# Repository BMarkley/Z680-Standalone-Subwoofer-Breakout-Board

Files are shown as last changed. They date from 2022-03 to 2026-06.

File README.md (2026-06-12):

# Z680-Standalone-Subwoofer-Breakout-Board
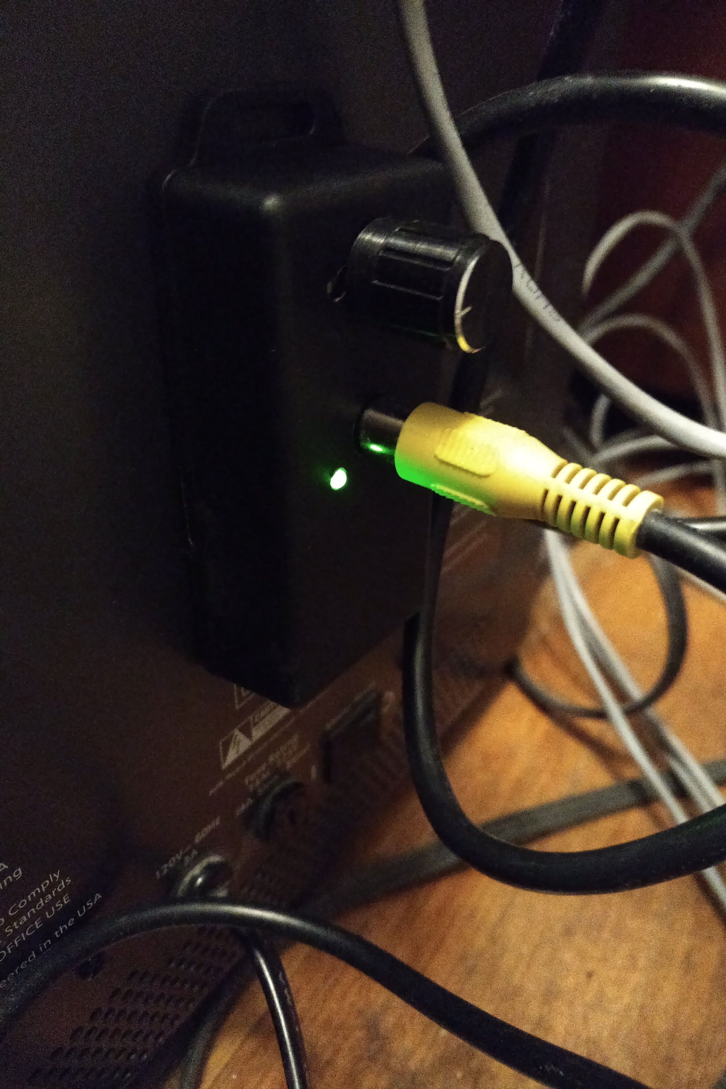
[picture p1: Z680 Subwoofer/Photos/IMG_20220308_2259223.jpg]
materials


This is a pcb and circuit for repurposing the subwoofer in the Z680 Logitech speakers system with an aftermarket receiver. Good for keeping these speakers in service after the control pod fails.

The PCB has been tested and works great, but the design is provided with no garauntees or warranty. You are liable for your own actions.

Notes on the LED and enclosure: 

1: The enclosure took a little trial and error so use your best judgement. The original plan for the LED was to lave it illuminate the phono jack but the LED I selected was not bright enough to work like that. I had to bring it to the exterior of the case. Inconsistencies in the photos are just the trial and error process. 

2: I needed to use 2 washers on the potentiometer to get the Dsub connector to be at the correct depth.

3: You may want to use double sided tape to secure the final product to the back of the subwoofer. 

Licensing: Open Hardware licensed under the Creative Commons BY-SA 4.0 License

You are free to:
Share — copy and redistribute the material in any medium or format
Adapt — remix, transform, and build upon the material
The licensor cannot revoke these freedoms as long as you follow the license terms.
Under the following terms:
Attribution — You must give appropriate credit, provide a link to the license, and indicate if changes were made. You may do so in any reasonable manner, but not in any way that suggests the licensor endorses you or your use.

NonCommercial — You may not use the material for commercial purposes.

ShareAlike — If you remix, transform, or build upon the material, you must distribute your contributions under the same license as the original.

No additional restrictions — You may not apply legal terms or technological measures that legally restrict others from doing anything the license permits.

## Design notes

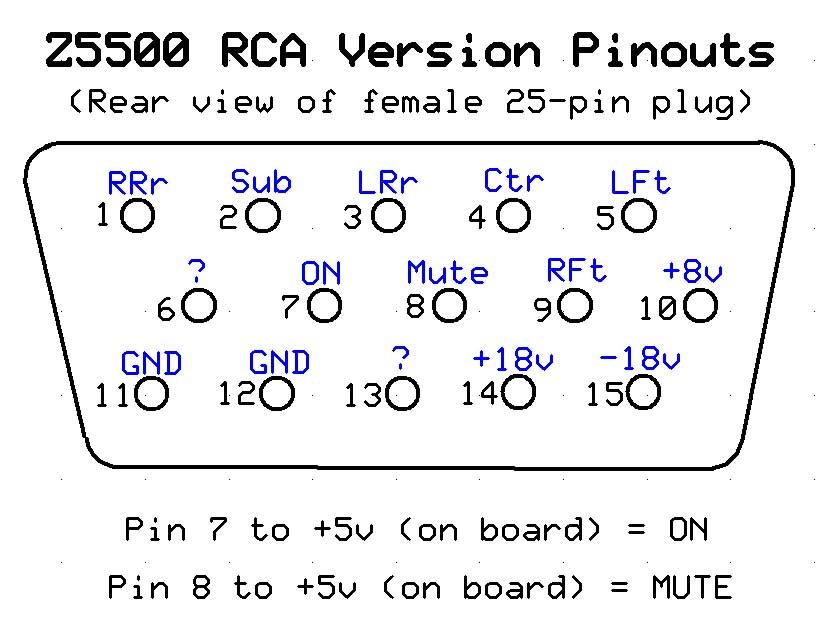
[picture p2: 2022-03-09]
Z680 Subwoofer/Development/z5500.jpg

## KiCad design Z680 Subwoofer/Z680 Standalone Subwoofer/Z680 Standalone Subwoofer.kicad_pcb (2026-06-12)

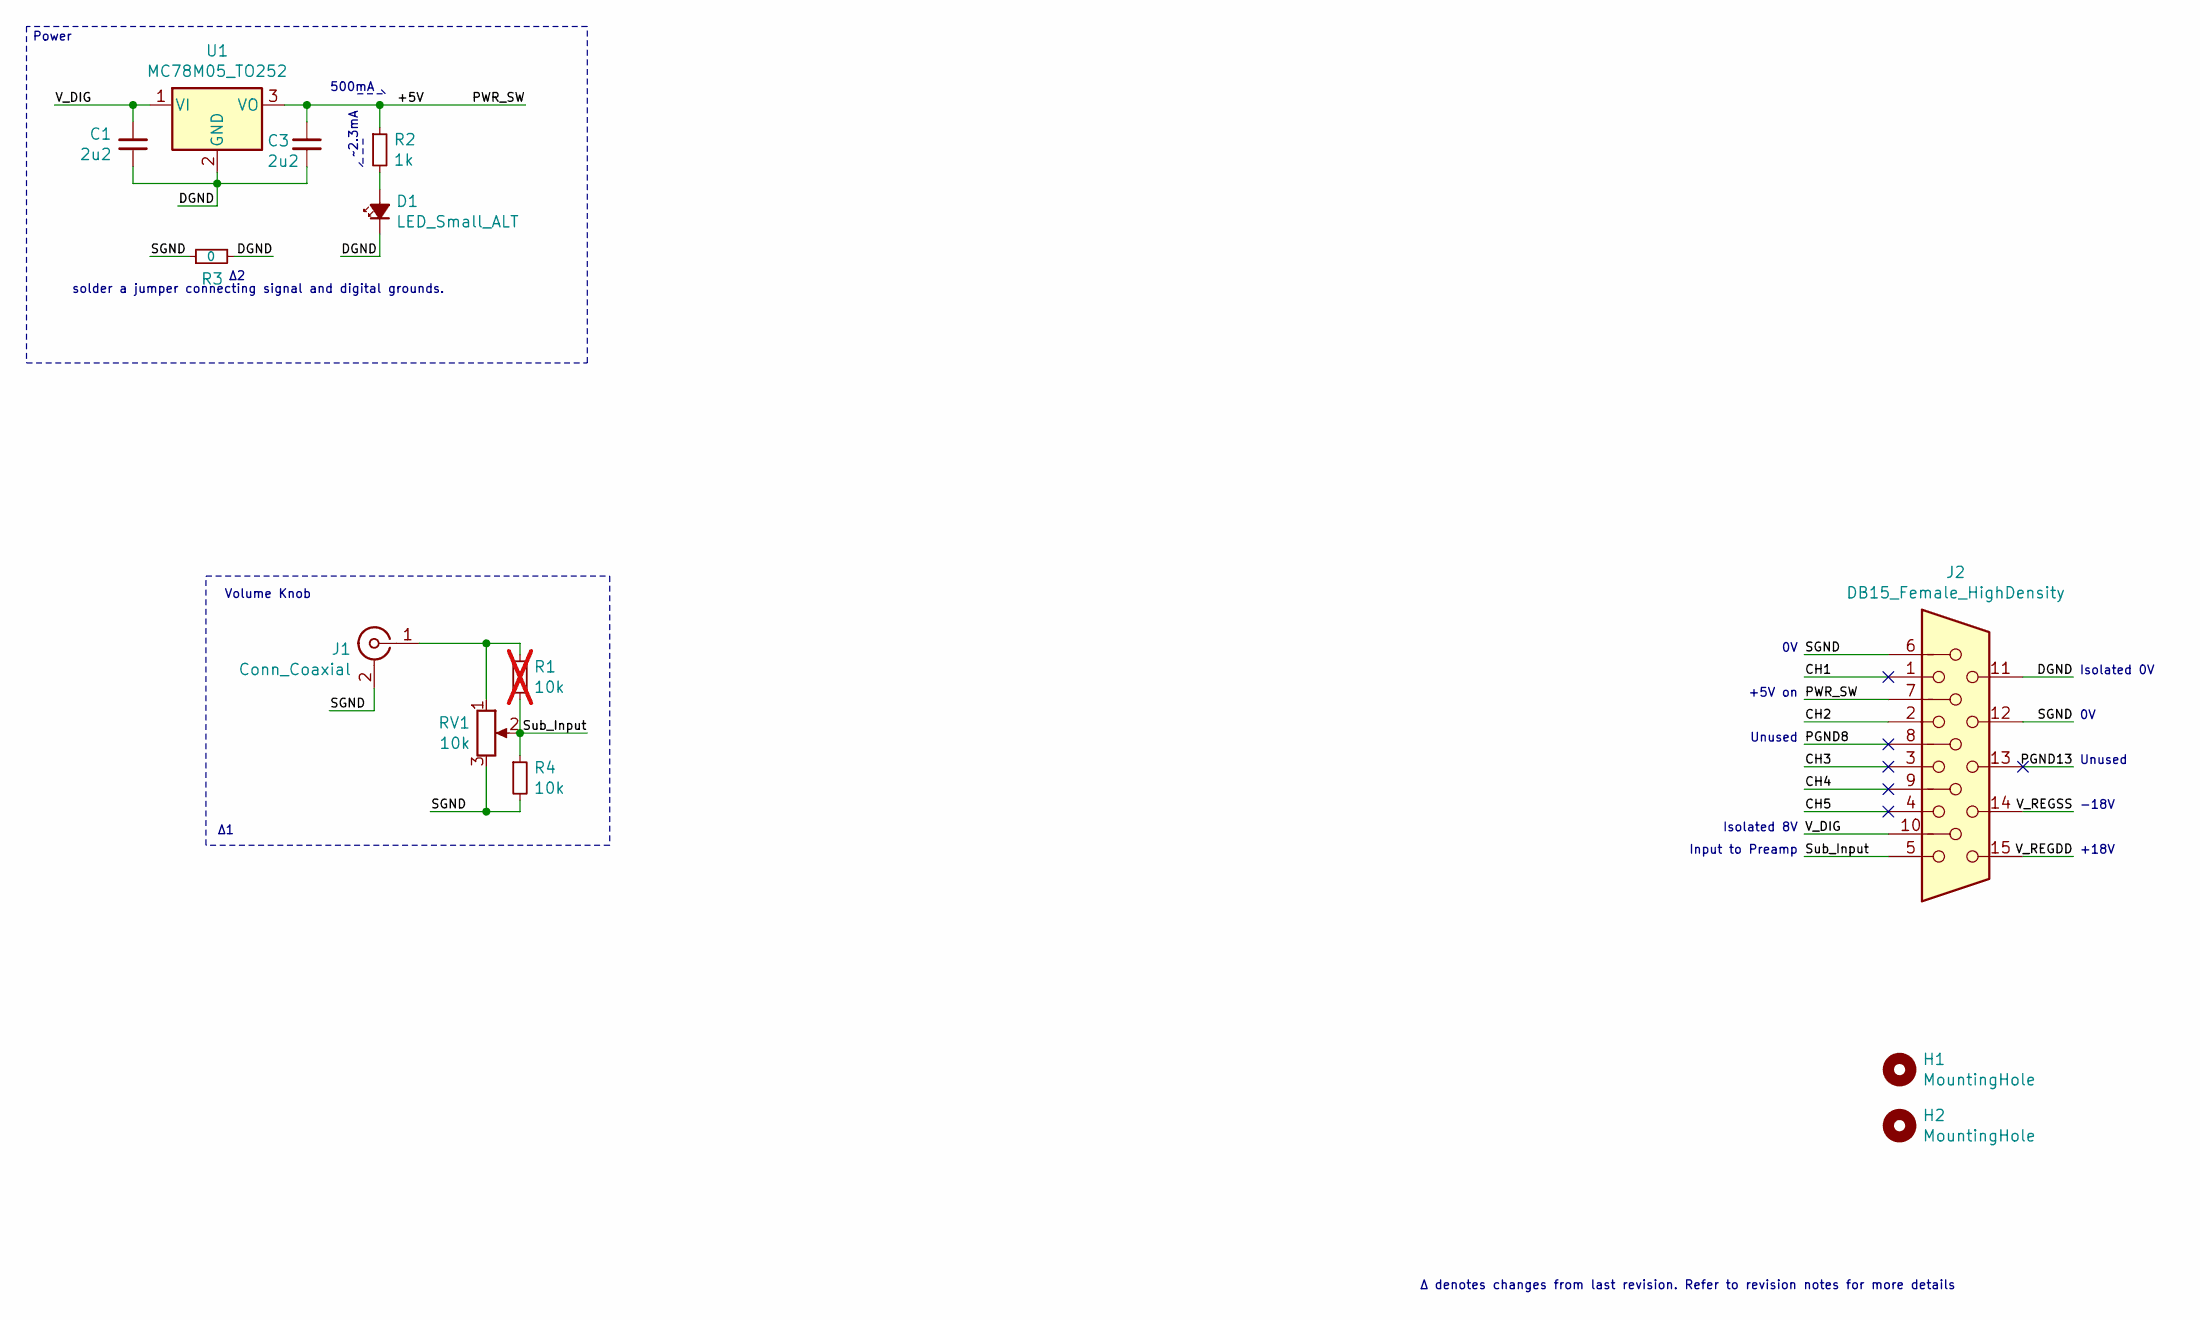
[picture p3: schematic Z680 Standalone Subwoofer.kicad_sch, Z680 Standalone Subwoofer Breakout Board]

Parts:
C1, C3: 2u2; C_0805_2012Metric
D1: LED_Small_ALT; LED_D3.0mm_Clear
H1, H2: MountingHole; MountingHole_2.2mm_M2
J1: Conn_Coaxial; RCJ-02
J2: DB15_Female_HighDensity; DSUB-15-HD_Female_Vertical_P2.29x1.98mm_MountingHoles
R1: 10k; R_0603_1608Metric; not fitted
R2: 1k; R_0603_1608Metric
R3: 0; R_0805_2012Metric
R4: 10k; R_0603_1608Metric
RV1: 10k; PotentiometerRecessed
U1: MC78M05_TO252; TO-252-2

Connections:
/+5V: C3.1, J2.7, R2.1, U1.3 (VO)
/CH1: J2.1
/CH2: J2.2
/CH3: J2.3
/CH4: J2.9
/CH5: J2.4
/DGND: C1.1, C3.2, D1.1 (K), J2.11, R3.2, U1.2 (GND)
/PGND8: J2.8
/PGND13: J2.13
/SGND: J1.2 (Ext), J2.6, J2.12, R3.1, R4.2, RV1.3
/Sub_Input: J2.5, R1.2, R4.1, RV1.2
/V_DIG: C1.2, J2.10, U1.1 (VI)
/V_REGDD: J2.15
/V_REGSS: J2.14
unnamed: D1.2 (A), R2.2
unnamed: J1.1 (In), R1.1, RV1.1

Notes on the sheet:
Input to Preamp
solder a jumper connecting signal and digital grounds.
~2.3mA
Volume Knob
-18V
Unused
500mA
Power
+18V
Δ denotes changes from last revision. Refer to revision notes for more details
Isolated 8V
+5V on
Isolated 0V

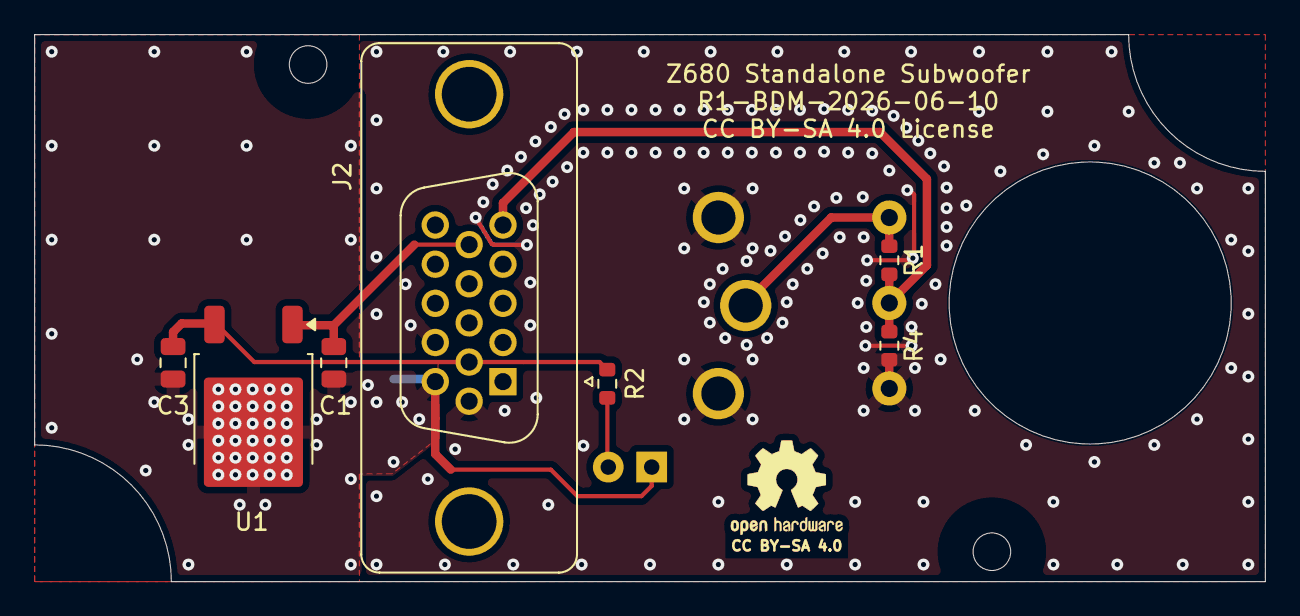
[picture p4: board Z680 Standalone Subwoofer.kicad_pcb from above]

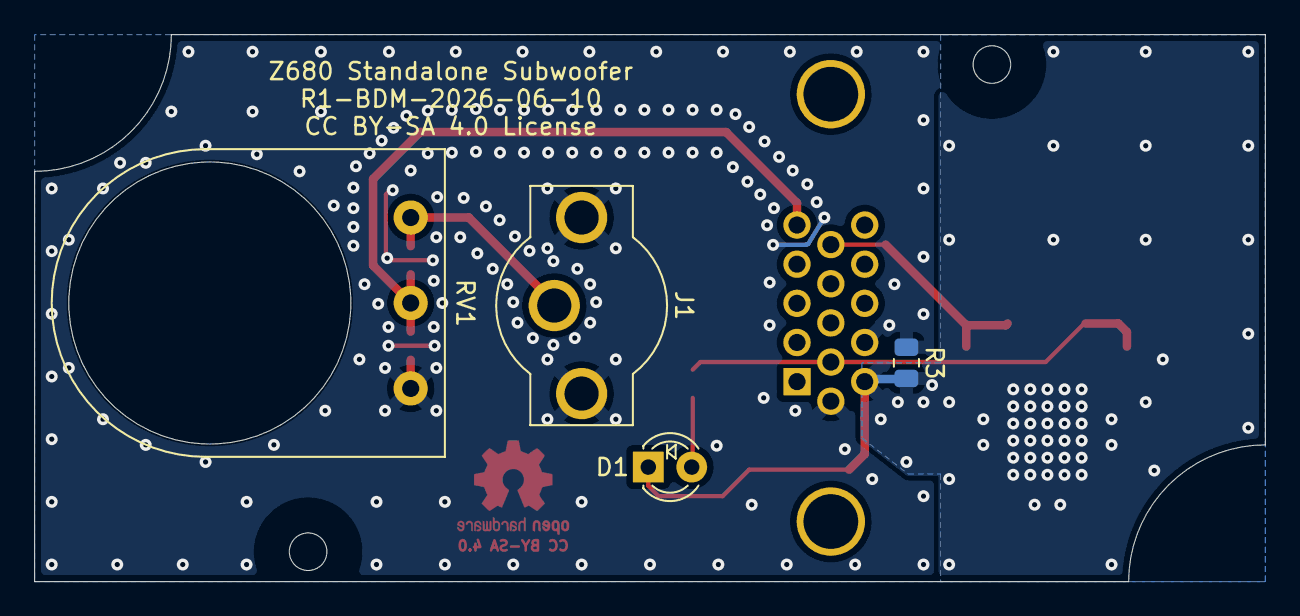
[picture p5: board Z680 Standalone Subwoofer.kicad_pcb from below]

Board: 2 copper layers, 72.0 x 32.0 mm, 13 parts (4 on the bottom side), 7 nets.

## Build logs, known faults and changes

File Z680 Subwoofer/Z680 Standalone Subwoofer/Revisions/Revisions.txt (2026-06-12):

Rev 1 of Z680 Standalone Breakout Board, by Brian Markley PENG RSE
-1: R1 is depopulated, and moved to R4 position. //This changes the logarithmic curve of the volume control gain to allow for more low end control. Adjust the value of R4 to change the curve as needed. This will depend on the reciever you are using and it's preamp gain. 10K works well for my Harmon Kardon AVR130 reciever.
-2: silkcreen of R3 is fixed.

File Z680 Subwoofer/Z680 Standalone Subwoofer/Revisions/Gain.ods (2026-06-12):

Wiper % | Old Parallel Resistance | New Parallel Resistance | Old Gain | New Gain | Old Resistor Value (kohm): | 10 | Slope | 1.26 | DB/10% @ Midrange
0 |  |  |  |  | New Resistor Value (kohm): | 10 | Slope | 1.84 | DB/10% @ Midrange
0.01 | 4.9748743718593 | 0.099009900990099 | -34.1085059158091 | -40.0855674440032
0.02 | 4.94949494949495 | 0.196078431372549 | -28.2146928174344 | -34.147996622665
0.03 | 4.9238578680203 | 0.29126213592233 | -24.8174019463904 | -30.7067264696222
0.04 | 4.89795918367347 | 0.384615384615385 | -22.4409723354371 | -28.2860937625666
0.05 | 4.87179487179487 | 0.476190476190476 | -20.6229883187959 | -26.4236805460463
0.06 | 4.84536082474227 | 0.566037735849057 | -19.1575082444203 | -24.9135428430249
0.07 | 4.81865284974093 | 0.654205607476636 | -17.9347007132588 | -23.6458468934142
0.08 | 4.79166666666667 | 0.740740740740741 | -16.8890257425885 | -22.5550503166595
0.09 | 4.76439790575916 | 0.825688073394495 | -15.978224882128 | -21.5988922270826
0.1 | 4.73684210526316 | 0.909090909090909 | -15.1734579397559 | -20.7485299588125
0.11 | 4.70899470899471 | 0.990990990990991 | -14.4541659149969 | -19.9834019984617
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

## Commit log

2026-06-10 Reuploaded Kicad files
    Reuploaded Kicad files in response to issue #1
    [Z680 Standalone Subwoofer-B_Cu.gbl, Z680 Standalone Subwoofer-B_Mask.gbs, Z680 Standalone Subwoofer-B_Paste.gbp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]
2026-06-10 Reupload Kicad Files
    Reupload kicad files in response to issue #1
    [Z680 Standalone Subwoofer.kicad_pcb, Z680 Standalone Subwoofer.sch]
2026-06-11 Kicad 10 upload
    Saved the files in Kicad 10.
    [Z680 Standalone Subwoofer.kicad_pcb, Z680 Standalone Subwoofer.kicad_sch]
2026-06-11 Updated Gerbers
    R2 was mislabelled C2 on the Gerbers for some reason.
    [Z680 Standalone Subwoofer-B_Cu.gbl, Z680 Standalone Subwoofer-B_Mask.gbs, Z680 Standalone Subwoofer-B_Paste.gbp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]
2026-06-12 Gain calculations for R1 of the PCB
    [Gain.ods]
2026-06-12 Revision 1
    Fix low end gain on volume
    [Gain.ods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]

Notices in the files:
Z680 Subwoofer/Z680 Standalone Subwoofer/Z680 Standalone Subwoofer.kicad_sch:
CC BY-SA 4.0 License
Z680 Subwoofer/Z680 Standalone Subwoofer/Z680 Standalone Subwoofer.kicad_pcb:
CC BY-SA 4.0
